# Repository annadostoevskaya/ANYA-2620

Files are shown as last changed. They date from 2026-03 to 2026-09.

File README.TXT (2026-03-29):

# ANYA-2620

Author: Kanat M. M. and Anna D. A.

Description:

---

Repo structure:

  Design Files - Main directory containing all design-related data such as schematics, PCB layouts, libraries, and project documentation.
  | Altium - Contains Altium Designer-specific files such as libraries, templates, and component models.
  | | Libraries - Stores schematic symbols and PCB footprints used in the project.
  | | | Models - Contains component models used in libraries.
  | | | | 3D - Stores 3D models for PCB visualization.
  | | Templates - Contains template files for Altium.
  | Documentation - Stores design documentation such as block diagrams and system descriptions.
  | V1I1 - Main working version 1 issue 1 of the project including schematics, PCB files, and firmware.
  | | Firmware - Contains firmware source code or related files.

  Development Files - Contains reference materials used during development, including datasheets, design guides, and software resources.
  | Competition and Similar Products - Information about competing or similar products.
  | Datasheets - Datasheets of components used in the project.
  | Design Guides - Application notes and hardware design guidelines.
  | Development Boards - Information about development boards used for prototyping.
  | Errata - Known issues, corrections, or design limitations.
  | Software - Software tools or utilities used during development.

  Released Files - Contains finalized and production-ready outputs such as manufacturing files, assembly data, and released documentation.
  | V1I1 - Final release version of the project.
  | | 3D - 3D models of the PCB assembly.
  | | Board Assembly - Assembly documentation and instructions.
  | | Firmware - Final firmware ready for deployment.
  | | PCB Manufacturing - Manufacturing files for PCB production.
  | | | Gerber Output - PCB layer files used for fabrication.
  | | | NC Drill Output - Drill files for PCB hole fabrication.
  | | Schematic - Final schematic documentation.
  | | Source Files - Source design files included in the release.

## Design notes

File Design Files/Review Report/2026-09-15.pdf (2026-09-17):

### КОНСОЛИДИРОВАННЫЙ ТЕХНИЧЕСКИЙ ОТЧЕТ

# Ревью печатной платы

## Схема, размещение, трассировка, защита и подготовка к производству

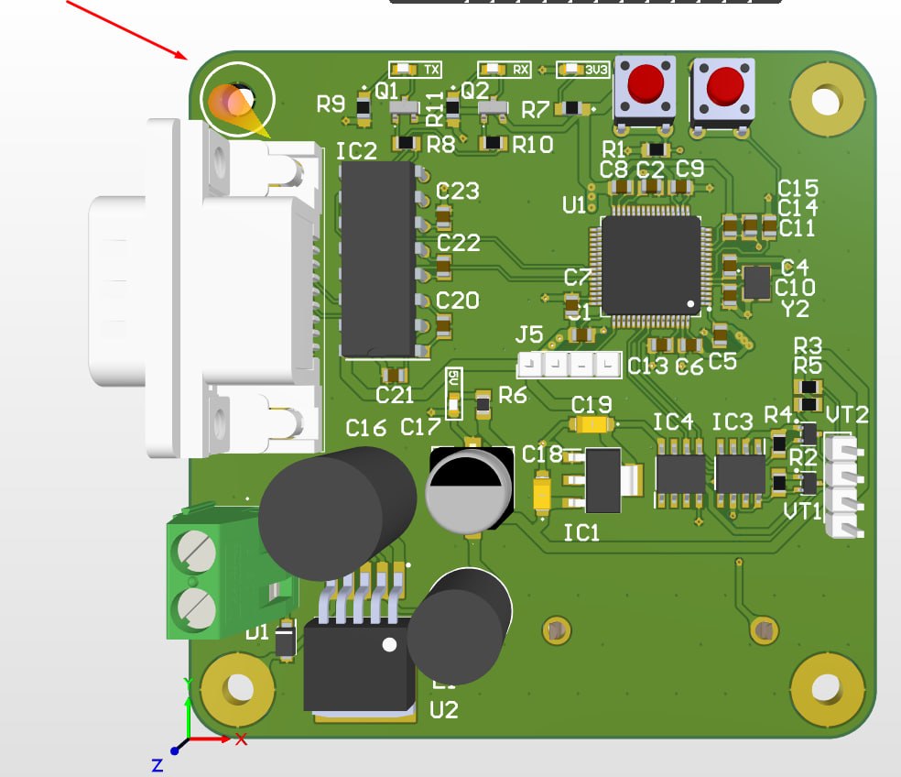
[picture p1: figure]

5

блокирующих тем

16

пунктов реестра

40

исходных кадров

## СТАТУС: ДО ЗАКРЫТИЯ P0 К ВЫПУСКУ НЕ ГОТОВО

Источник: Telegram-экспорт от 15.09.2026; технические сообщения датированы 27-28.07.2026.

ОТЧЕТ ПО РЕВЬЮ PCB | 15.09.2026 | Источник: экспорт переписки
Рабочий документ - закрывать пункты по критериям приемки | 2 / 9

# 01 Резюме и границы ревью

Переписка указывает не на единичные косметические правки, а на системные темы: развязка питания, возвратные токи, защитные цепи и правила соединения полигонов. Их нужно закрыть до повторного выпуска gerber.

### Главный вывод

Сначала исправить пять пунктов P0: локальную развязку, положение защитного диода, ESD на доступных разъемах, питание +3.3 В и непрерывность GND. После этого - переразводка DC/DC, via и нормализация ширин.

## Рекомендуемый порядок

- 1. Зафиксировать требования: входные напряжения, токи, уровни I/O, доступные пользователю разъемы и ограничения сборки.
- 2. Исправить схему и BOM: развязка, защитные/ESD-компоненты, решение по MOSFET, test points.
- 3. Перекомпоновать критические узлы и заново провести силовые/земляные цепи; затем применить единые правила ко всей плате.
- 4. Прогнать ERC/DRC, проверить gerber, маску, шелкографию и получить повторное peer review.

## Приоритеты

### P0 - блокер

Риск отказа, повреждения
или некорректной работы.
Закрыть до выпуска.

### P1 - важно

Существенно влияет на
SI/PI, тепло,
технологичность или
надежность.

### P2 - улучшение

Улучшает запуск, сервис
и читаемость; согласовать
до финала.

### DEC - решение

Нужны
требования/расчет; не
выполнять как
механическую правку.

### Ограничения

Отчет составлен только по тексту и 40 изображениям из истории чата. Исходные файлы схемы/PCB, stack-up, net classes, BOM, даташиты, результаты ERC/DRC и требования производителя не предоставлены. Поэтому критерии ниже являются планом верификации, а не подтверждением готовности конструкции.

Рабочий документ - закрывать пункты по критериям приемки | 3 / 9

# 02 Реестр замечаний - часть 1

Пункты R-01 - R-07 охватывают блокирующие электрические риски и силовой/тепловой контур.

ID | Приоритет | Замечание / действие | Критерий закрытия | Источник
R-01 | P0 Блокер | Локальная развязка питания Добавить керамику 100 нФ рядом с выводами питания в узлах, где сейчас показаны только электролиты или нет локального конденсатора. | 100 нФ установлен у каждого указанного узла; контур вывод питания - C - GND минимален. | IMG-01..03, 05..06
R-02 | P0 Блокер | Положение защитного диода D1 Перенести диод максимально близко к защищаемому выводу/узлу и дать ему короткий прямой путь в землю. | Ток импульса уходит в диод до входа микросхемы; подтверждено трассировкой и проверкой правил. | IMG-09..11
R-03 | P0 Блокер | ESD-защита доступных I/O Поставить специализированные TVS/ESD-диоды на цифровые входы/выходы и разъемы, доступные пользователю. | Выбраны компоненты под каждый уровень; проверены VRWM, емкость и токовый путь к земле. | IMG-39; чат 01:20-01:30
R-04 | P0 Блокер | Развязка шины +3.3 В Проверить питание MAX3232, RTC и прочих потребителей +3.3 В; добавить локальные конденсаторы по даташитам. | У каждого VCC есть обязательная развязка; номиналы и количество сверены с даташитами. | IMG-03, 05..06
R-05 | P0 Блокер | Непрерывность GND и возвратные токи Убрать лишние дорожки GND, использовать сплошные полигоны, не разрезать опорную землю сигнальными маршрутами. | Для ключевых сигналов есть непрерывный путь возврата; полигоны залиты без островов и узких шеек. | IMG-12, 14, 23, 30
R-06 | P1 Важно | Переходные GND без термобарьеров Для stitching-via и via у развязывающих конденсаторов применить сплошное подключение; рядом с C использовать по несколько via. | Нет thermal relief на непаяемых via; импеданс GND минимален; правило применено по всей плате. | IMG-15..17, 21, 29, 31..33
R-07 | P1 Важно | Силовой и тепловой контур DC/DC Заменить узкие участки силовых цепей медными заливками; добавить тепловые via вокруг крупной площадки. Via в pad - только если разрешено технологией/даташитом. | Ширины выдерживают расчетный ток; тепловой путь подтвержден; требования сборщика по via учтены. | IMG-34..36

Все пункты считаются открытыми, пока не приложены новая схема/layout, результаты проверок и подтверждение критерия закрытия.

Рабочий документ - закрывать пункты по критериям приемки | 4 / 9

# 02 Реестр замечаний - часть 2

Пункты R-08 - R-16 закрывают правила трассировки, механику, тестопригодность и оставшееся инженерное решение.

ID | Приоритет | Замечание / действие | Критерий закрытия | Источник
R-08 | P1 Важно | Ширины дорожек по классам Разделить power/signal-классы, убрать случайные переходы ширины и неоправданно широкие цифровые перемычки. | Ширины заданы правилами; нет необоснованных сужений/расширений; DRC чистый. | IMG-13, 20, 22, 26
R-09 | P1 Важно | Компоновка и ориентация ИС Пересмотреть участок level shifter/интерфейса; поворот ИС на 90 градусов может сократить маршруты и сохранить землю. | Маршруты короче, пересечений меньше, полигон GND непрерывен; решение сравнено до/после. | IMG-24..28
R-10 | P1 Важно | Положение локального конденсатора Рассмотреть перенос отмеченного конденсатора ближе к обслуживаемому узлу. | Связь с выводом питания короткая; размещение соответствует даташиту и не ухудшает сборку. | IMG-37
R-11 | P1 Важно | Маскирование переходных Закрыть паяльной маской все переходные, для которых не требуется открытая площадка. | Настройка tenting единообразна; исключения документированы; проверены gerber mask layers. | IMG-07; чат 01:27
R-12 | P1 Важно | Крепежные отверстия Проверить единообразие четырех отверстий: тип, металлизация, связь с GND, keepout и отступ меди. | Все отверстия соответствуют механике корпуса и одному согласованному правилу реализации. | IMG-08, 38
R-13 | P2 Улучшение | Контрольные точки Добавить test points до и после DC/DC, на шины питания, интерфейсы и диагностически важные линии. | Точки доступны щупу, подписаны, не мешают сборке; перечень согласован с планом запуска. | Чат 21:37-21:41
R-14 | P2 Улучшение | Пользовательские функции По необходимости вывести 1-2 LED, несколько GPIO и кнопку USER. | Решение принято по требованиям изделия; лишние функции исключены либо добавлены с обозначениями. | IMG-18; чат 21:42-21:44
R-15 | P2 Улучшение | Шелкография и версия Исправить наложения/читаемость обозначений; добавить версию платы. | Все reference designators читаемы после сборки, не заходят на pads; версия видна на PCB. | IMG-40; чат 01:33-01:34
R-16 | DEC Решение | Топология ключей Проверить предложение заменить текущие ключи на N-channel MOSFET. Это не готовое исправление без требований к полярности, уровням и потерям. | Есть расчет/обоснование выбранной топологии, уровней управления, RDS(on), токов и fail-safe состояния. | IMG-04

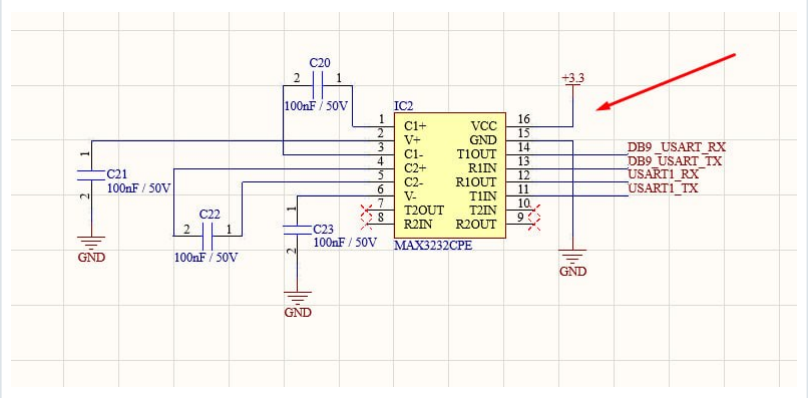
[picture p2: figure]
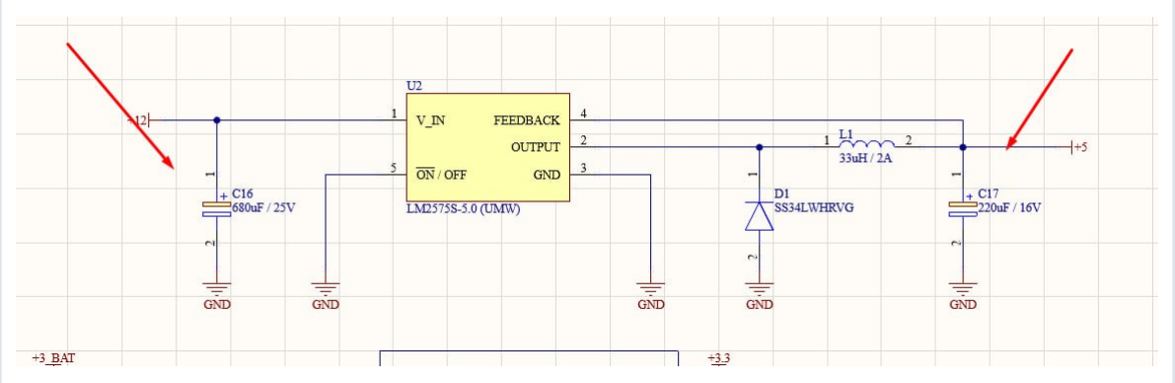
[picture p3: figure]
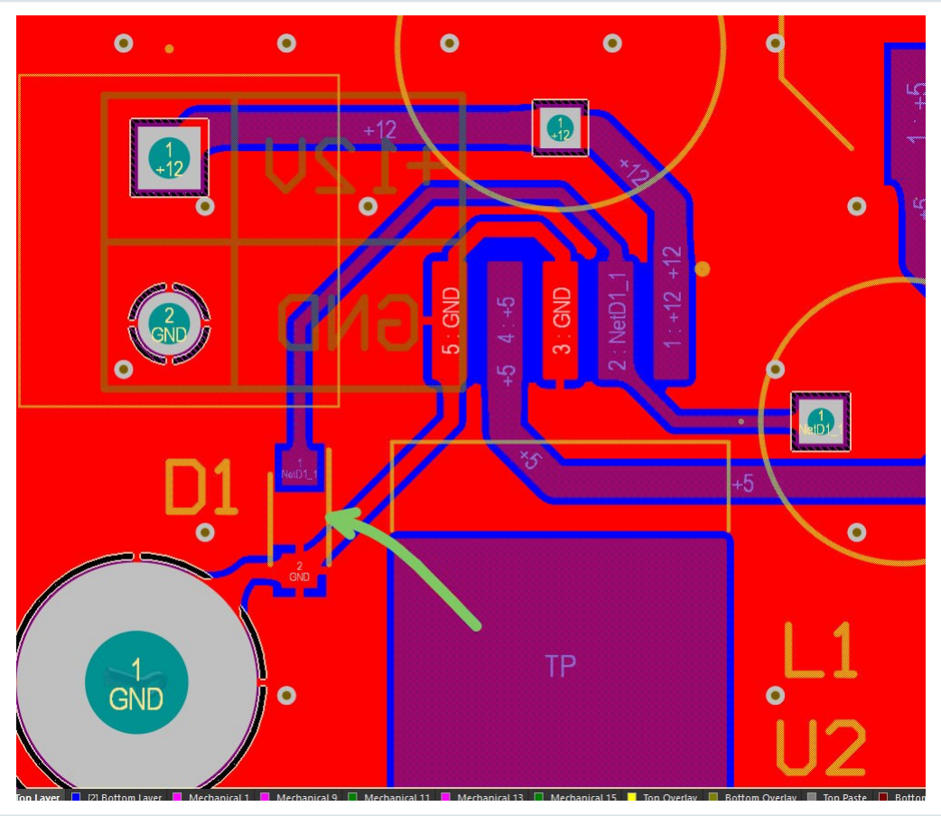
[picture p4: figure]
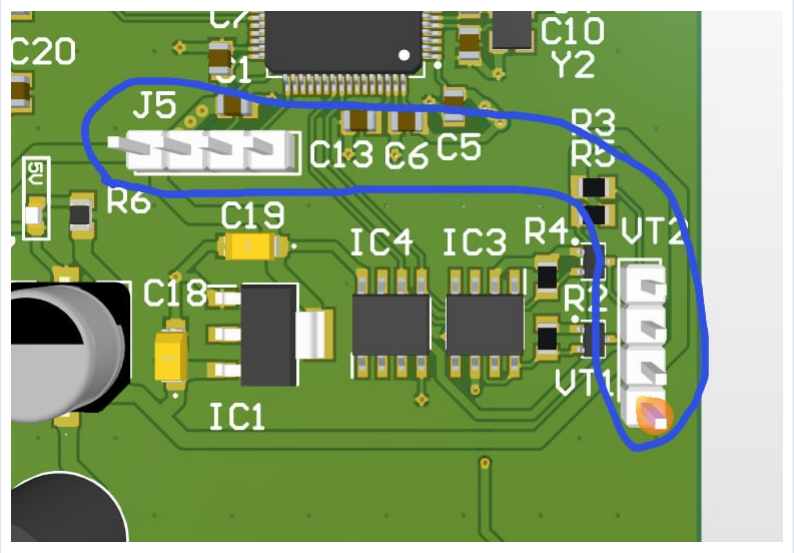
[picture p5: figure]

Рабочий документ - закрывать пункты по критериям приемки | 5 / 9

# 03 Питание и защита

Критический принцип: конденсатор или защитный компонент работает только при коротком, низкоиндуктивном пути именно к тому выводу, который он обслуживает.

### IMG-01 DC/DC: добавить 100 нФ

Керамика требуется рядом с силовым узлом в дополнение к объемной емкости.

### IMG-03 +3.3 В без локальной развязки

Проверить VCC интерфейсной ИС и добавить конденсаторы по даташиту.

### IMG-10 D1 слишком далеко

Перенести диод к защищаемому выводу; путь к GND сделать коротким и прямым.

### IMG-39 Доступные пользователю разъемы

J5 и боковой header отмечены как обязательные точки ESD-защиты.

### Проверка выбора ESD

Для каждой линии сверить максимальное рабочее напряжение, VRWM, напряжение ограничения, паразитную емкость, полосу интерфейса, корпус и реальный путь разрядного тока к земле. Формулировка из чата о разных уровнях напряжения вынесена в обязательный критерий.

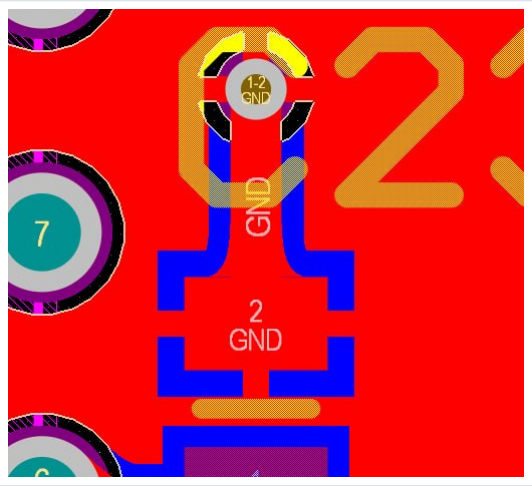
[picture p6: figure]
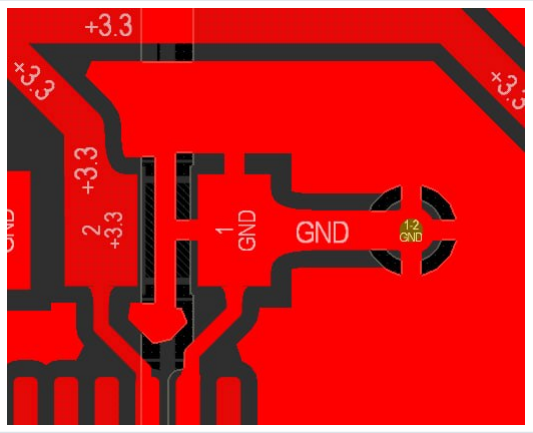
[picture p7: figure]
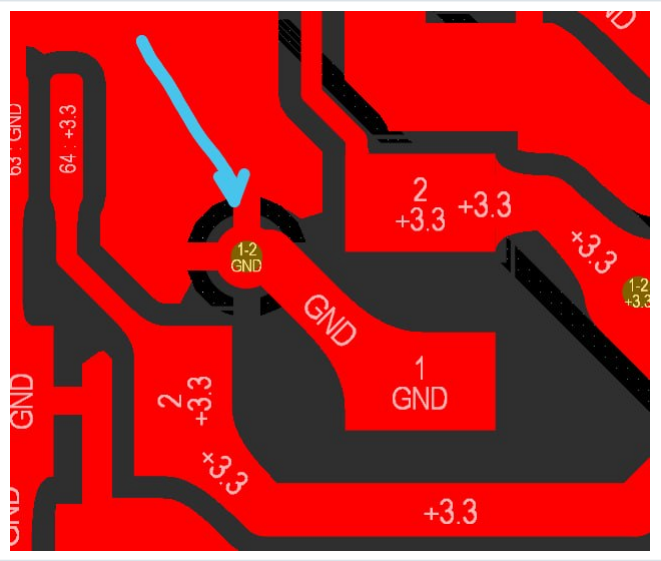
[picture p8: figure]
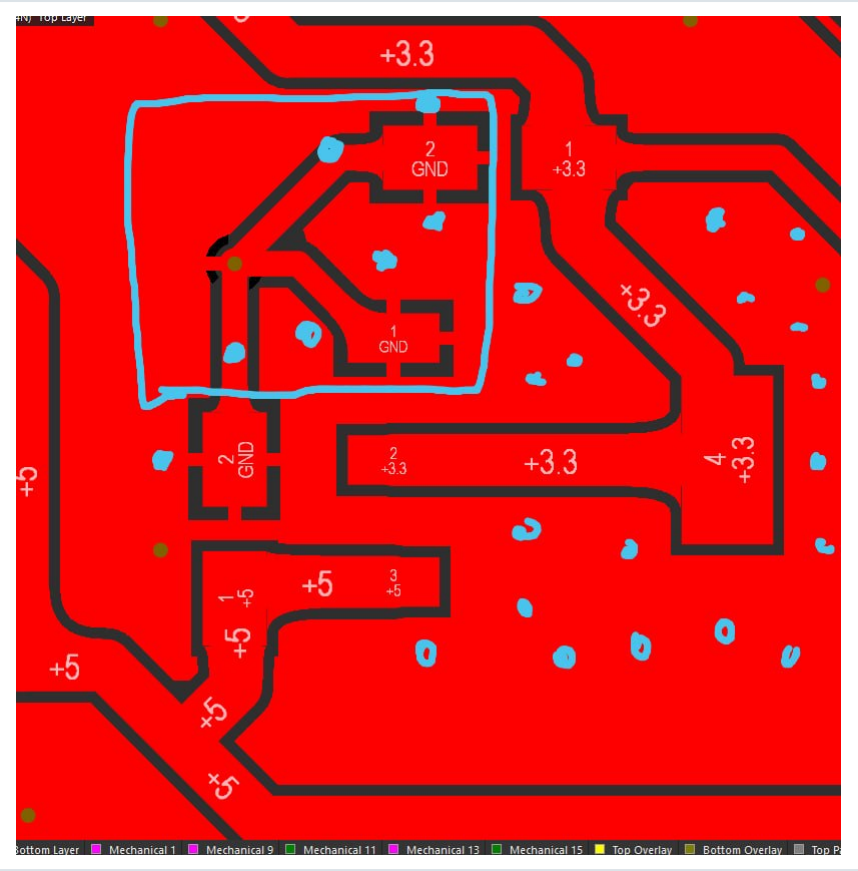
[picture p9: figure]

Рабочий документ - закрывать пункты по критериям приемки | 6 / 9

# 04 Земля, полигоны и DC/DC

Повторяющаяся тема ревью - заменить длинные GND-дорожки и thermal relief на сплошное подключение к полигону, а около развязки и силовых узлов дать несколько коротких via.

### IMG-15 Via у развязки

Показан нежелательный длинный GND-путь с thermal relief.

### IMG-21 Два GND via рядом с C

Предпочтителен короткий сплошной путь через несколько переходных.

### IMG-30 Рваная земля

Участок требует сплошной заливки без узких шеек и лишней дорожки.

### IMG-36 DC/DC 3.3 В

Заливка вместо дорожек; via рядом с C и вокруг силовой площадки.

### Важная оговорка по via

Рекомендация из переписки: тепловые via размещать рядом с крупной площадкой DC/DC, а не автоматически внутри land pattern. Via-in-pad допустим только при явном разрешении производителя платы/сборки и даташита корпуса.

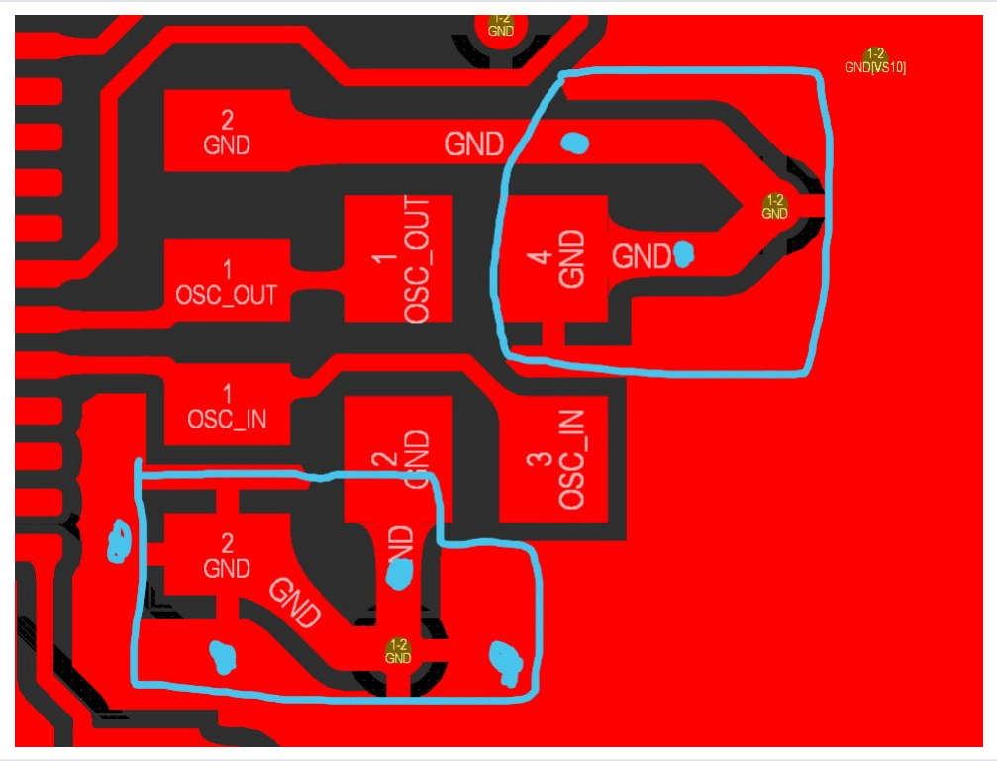
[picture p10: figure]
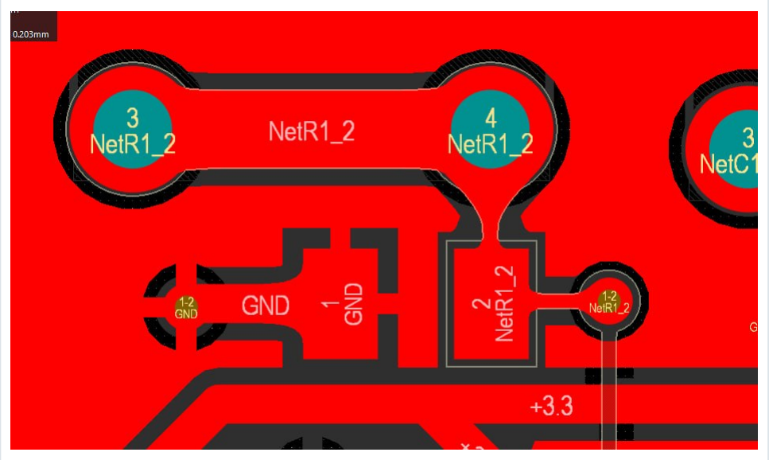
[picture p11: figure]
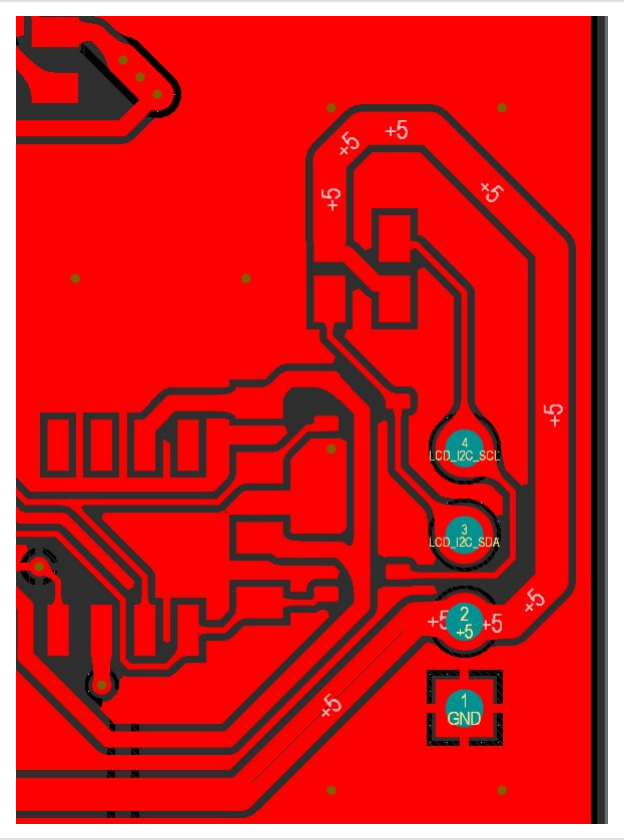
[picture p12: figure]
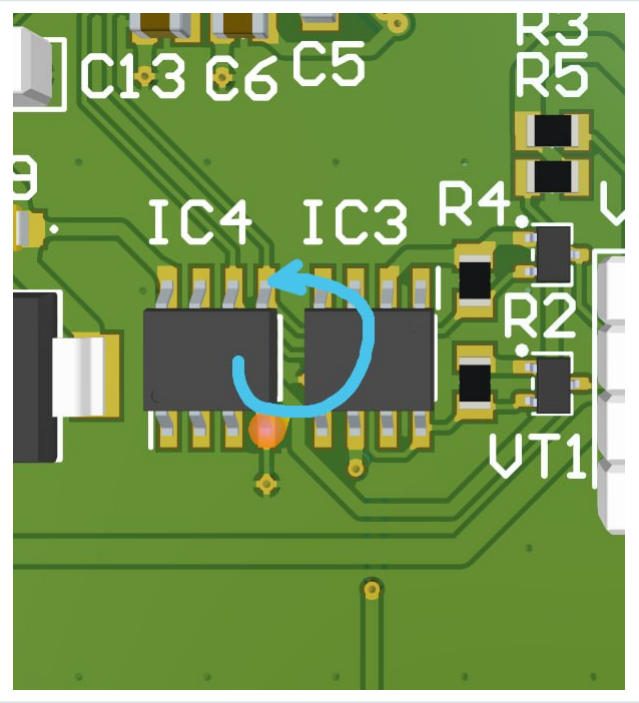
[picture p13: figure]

Рабочий документ - закрывать пункты по критериям приемки | 7 / 9

# 05 Трассировка и компоновка

Ширины должны следовать назначению сети, а не локальным ручным решениям. Для цифровых сигналов избыточная ширина не компенсирует плохой возвратный путь.

### IMG-20 Скачок ширины

Отмечен переход от очень широкой к узкой дорожке без понятного основания.

### IMG-23 GND отдельными трассами

Участок следует переработать под нормальную заливку и stitching.

### IMG-24 Плотный маршрут +5 В

Предложено пересмотреть размещение, чтобы сократить обход и не резать землю.

### IMG-27 Поворот микросхемы

Поворот на 90 градусов рассматривается как способ укоротить цифровые маршруты.

### Правило на будущее

Создать net classes минимум для силовых линий, обычных сигналов и чувствительных/быстрых интерфейсов. Настроить ширины, зазоры, via и правила полигона централизованно, затем убрать локальные исключения без обоснования.

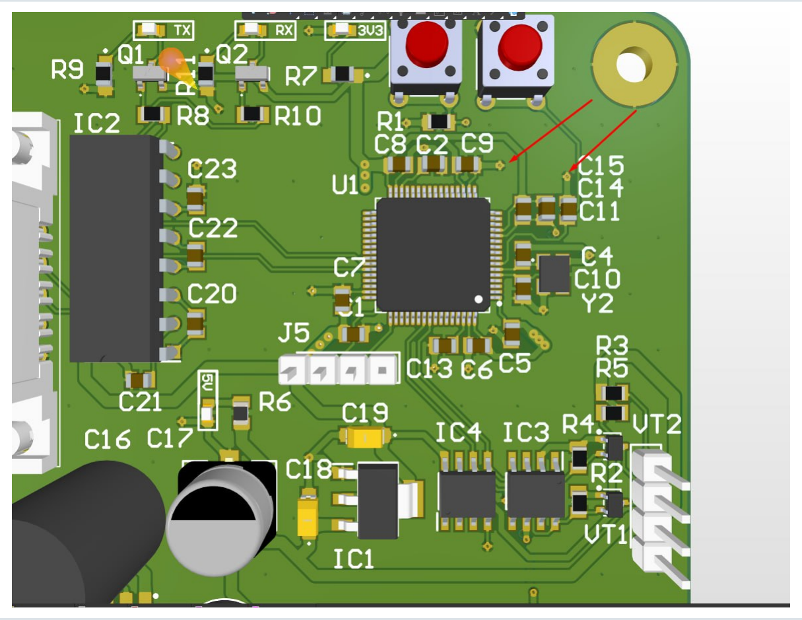
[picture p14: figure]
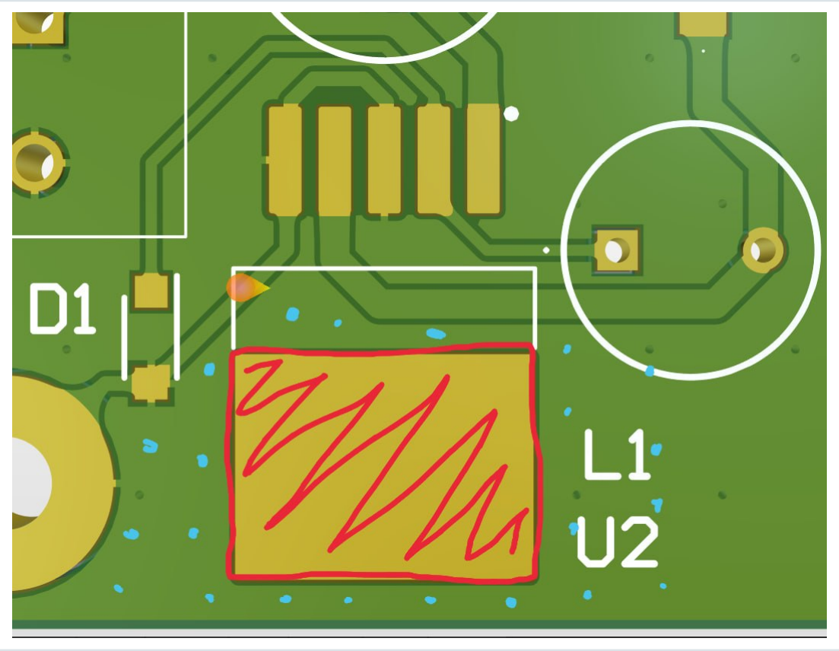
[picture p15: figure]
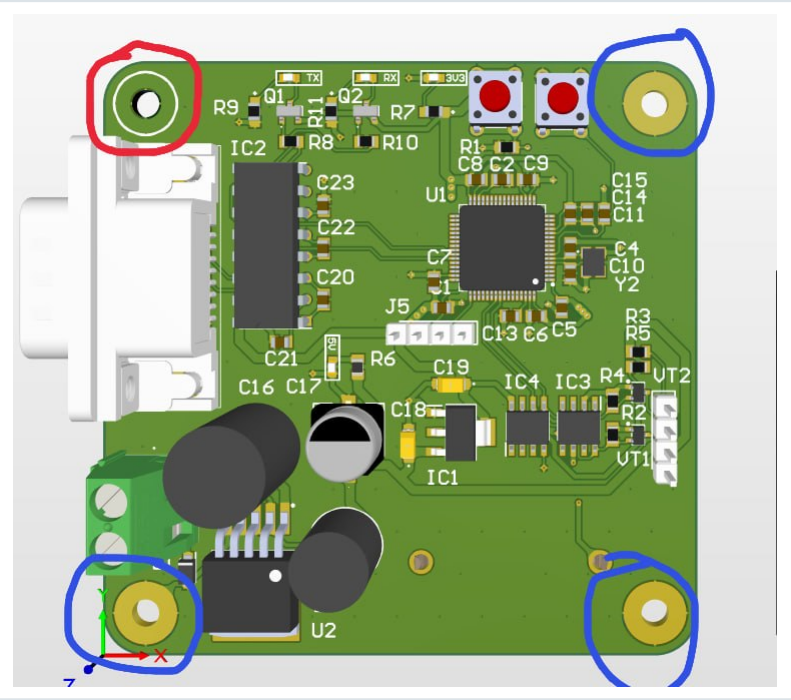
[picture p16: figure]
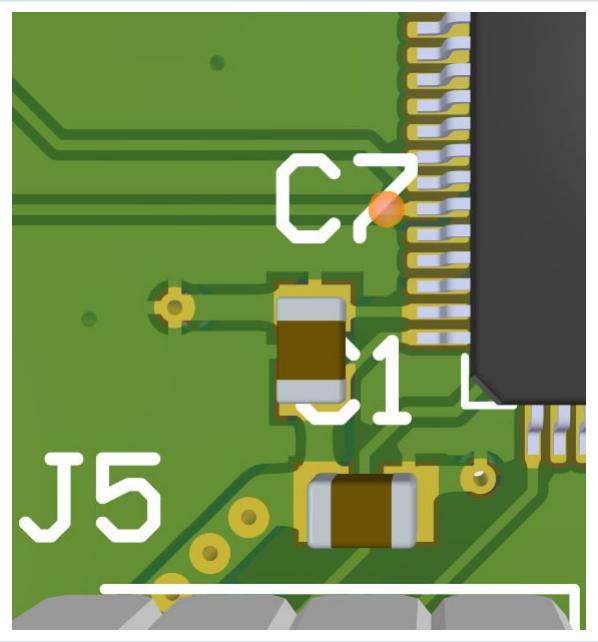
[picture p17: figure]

Рабочий документ - закрывать пункты по критериям приемки | 8 / 9

# 06 Технологичность и сервис

Эти пункты редко ломают прототип немедленно, но заметно влияют на отладку, повторяемость производства и риск ошибок при сборке.

### IMG-07 Tenting переходных

Закрыть маской все via, кроме документированных технологических исключений.

### IMG-35 Тепловые via рядом с pad

Ревью предлагает via вокруг силовой зоны, не на самой посадочной площадке.

### IMG-38 Четыре крепежных отверстия

Проверить одинаковый тип, металлизацию/изоляцию, keepout и связь с GND.

### IMG-40 Шелкография

Обозначения C7/C1/J5 конфликтуют с графикой и элементами; добавить версию платы.

### Test points

Минимальный набор: вход каждого DC/DC, выход каждой шины, GND рядом с силовыми TP, ключевые интерфейсы и диагностические LED-линии. Не требуется выводить каждую цифровую сеть - перечень должен соответствовать плану bring-up.

Рабочий документ - закрывать пункты по критериям приемки | 9 / 9

# 07 План закрытия и повторной проверки

Готовность подтверждается не фразой «исправлено», а комплектом проверяемых артефактов.

## Чек-лист выпуска

Этап | Проверка | Ответственный | Доказательство | OK
A | Схема/BOM: все P0 и решение R-16 закрыты; номиналы и part numbers подтверждены. | Схемотехник | PDF схемы, BOM, комментарии к расчетам |
B | Размещение: D1, C и ESD стоят у обслуживаемых выводов; DC/DC и shifter перекомпонованы. | PCB designer | Скриншоты до/после, ссылки на layout |
C | Трассировка: net classes, непрерывный GND, solid via, stitching и силовые заливки применены. | PCB designer | DRC rules/report, stack-up, copper views |
D | DFM: маска, отверстия, шелкография, версия, via-in-pad и требования сборки проверены. | PCB + производитель | Gerber viewer, fab notes, DFM report |
E | Bring-up: TP достаточны для питания и интерфейсов; подготовлен порядок первого включения. | HW/validation | Test plan и карта TP |
F | Независимое повторное ревью выполнено; оставшиеся отклонения задокументированы и приняты. | Reviewer | Закрытый реестр R-01..R-16 |

### Рекомендуемый gate

Не выпускать новый комплект gerber, пока P0 не закрыты и не пройдены ERC/DRC. После P0 провести второе ревью именно по изображениям copper/mask/silkscreen и по отчетам проверок; затем закрыть P1 или оформить согласованные отклонения.

## Что приложить к следующему ревью

- PDF схемы с обозначениями и номиналами; актуальный BOM с part numbers защитных элементов.
- Скриншоты всех copper layers, маски и шелкографии; stack-up и таблицу net classes.
- ERC/DRC отчеты, gerber/drill preview, список исключений и DFM-ответ производителя.
- Короткую таблицу «R-ID - изменение - доказательство - статус».

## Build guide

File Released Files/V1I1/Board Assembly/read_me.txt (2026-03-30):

Place following files here:

- Pick and Place
- Bill of Materials (grouped by component type)
- Component reference BOM (each component on one line: Designator, Description, Manufacturer 1,
  Manufacturer, Part Number 1, Package / Case, Supplier 1, Supplier Part Number 1)
- TOP and BOTTOM VIEW (shows board outline, assembly layer, TOP + BOTTOM layers)
- Mechanical Drawing (Board dimensions, holes position, ..)
- TOP and BOTTOM Assembly Drawing (Component position with Reference Designator)
- 3D Model

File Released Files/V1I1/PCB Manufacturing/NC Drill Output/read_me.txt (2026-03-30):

Place here drill files and documents which explain it (e.g. for HDI PCB you can put here pdf showing drills for each layer pair)

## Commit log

2026-03-30 master :: Altium Project
    [ANYA_2620_PROJECT.SchDoc, Anya_2620_V1_I1.PrjPcb, COVER PAGE.SchDoc]
2026-03-30 master :: COVER PAGE
    [COVER PAGE.SchDoc, REVISION HISTORY.SchDoc]
2026-03-30 master :: LCD
    [ANYA_2620_PROJECT.SchDoc, Anya_2620_V1_I1.PrjPcb, COVER PAGE.SchDoc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]
2026-03-30 master :: update diag, update step file lcd-i2c
    [COVER PAGE.SchDoc]
2026-03-31 master :: STM32H503RBT6
    [ANYA_2620_PROJECT.SchDoc, Anya_2620_V1_I1.PrjPcb, COVER PAGE.SchDoc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]
2026-04-02 master :: lcd, header
    [ANYA_2620_PROJECT.SchDoc, Anya_2620_V1_I1.PcbDoc, Anya_2620_V1_I1.PrjPcb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]
2026-04-02 master :: rename
    [ANYA_2620_PROJECT.SchDoc, Anya_2620_V1_I1.PrjPcb, Anya_2620_V1_I1.SchDoc]
2026-04-02 lcd i2c conn
    [LCD.SchDoc]
2026-04-03 master :: connectors, lcd
    [Anya_2620_V1_I1.PrjPcb, Anya_2620_V1_I1.SchDoc, COVER PAGE.SchDoc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]
2026-04-04 master :: power, rtc and fram
    [Anya_2620_V1_I1.PrjPcb, Anya_2620_V1_I1.SchDoc, COVER PAGE.SchDoc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]
2026-04-14 master :: finished all major components and start passives
    [Anya_2620_V1_I1.PrjPcb, Anya_2620_V1_I1.SchDoc, FRAM_AND_RTC.SchDoc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]
2026-04-16 master :: passive
    [Anya_2620_V1_I1.PrjPcb, MCU_SYS.SchDoc]
2026-05-04 master :: library loader probe
    [COVER PAGE.SchDoc, LCD_I2C.SchDoc]
2026-07-19 master :: restore
    [Anya_2620_V1_I1.PrjPcb, Anya_2620_V1_I1.SchDoc, FRAM_AND_RTC.SchDoc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]
2026-07-21 master :: power and nrst
    [Anya_2620_V1_I1.PrjPcb, PCB1.PcbDoc, Sheet1.SchDoc]
2026-07-23 master :: prepare for placement
    [Anya_2620_V1_I1.PcbDoc, Anya_2620_V1_I1.PrjPcb, Anya_2620_V1_I1.SchDoc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]
2026-07-23 master :: led indicator
    [Anya_2620_V1_I1.PcbDoc, Anya_2620_V1_I1.PrjPcb, COVER PAGE.SchDoc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]
2026-07-24 master :: placement
    [ANYA_2620_V1_I1.SchDoc, Anya_2620_V1_I1.PcbDoc, Anya_2620_V1_I1.PrjPcb]
2026-07-25 master :: routing
    [ANYA_2620_V1_I1.SchDoc, Anya_2620_V1_I1.PcbDoc]
2026-07-25 master :: silkscreen
    [Anya_2620_V1_I1.PcbDoc]
2026-10-21 master :: board outline
2026-10-23 master :: 3v3, 5v
2026-10-28 master :: routeing 3v3 5v
2026-11-03 Упорядочить проект и перенести закупочный BOM в KiCad
    - Разделить текущие исходники, прошивку, производственные файлы,
    документацию и архивы по hardware, firmware, manufacturing, docs и archive.
    - Обновить пути библиотек, 3D-моделей и экспорта; сохранить историю KiCad
    и материалы прежней версии Altium.
    - Сохранить текущие изменения схемы и платы, включая корпуса 1210
    для C2/C4/C5 и согласованные модели закупаемых ко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
